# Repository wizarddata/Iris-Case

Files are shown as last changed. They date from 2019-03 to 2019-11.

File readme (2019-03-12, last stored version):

As of 3/12/2019 this case has not been tested. If you print one of these for a build let me know and I'1l remove this warning.

This is a tenting case for the Iris. This case is designed for 3/32 silicon feet on the underside of the PCB. 

You'll need to get the pro micro as close as you can to the PCB, the cheapest way to do this is remove the black plastic from the pin headers. 
Be sure to trim switch legs under the micro and use a piece of tape for electrical insulation.

Uses standard 3mm hardware. You'll need four (4) bolts (I recommend thumbscrews) 16mm - 20mm long, four (4) nuts, and eight (8) 5mm diameter magnets for each half. 

The magnets will need to be glued in place. The hat is a press fit into the switchplate and there are provisions to add some adhesive after assembly if necessary.

To improve traction, wrap a #30 rubber band around each leg lengthwise. Compatible with Ergodox EZ legs as well.

The units of these models are in inches.

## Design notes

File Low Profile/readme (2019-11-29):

These files are not compatible with the rest of the files in this repo.

This is a tenting case for the Iris. This case is designed for 3/32 silicon feet on the underside of the PCB.

Uses standard 3mm hardware. You'll need bolts (I recommend thumbscrews) about 16mm long.

To improve traction, wrap a #30 rubber band around each leg lengthwise.

EDIT 15-Mar-2019 - Case updated to allow for more room for the pro micro.

https://a360.co/2Y1DsCQ

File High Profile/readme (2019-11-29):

This is a tenting case for the Iris. This case is designed for 3/32 silicon feet on the underside of the PCB. 

Uses standard 3mm hardware. You'll need four (4) bolts (I recommend thumbscrews) 16mm long, four (4) nuts, and eight (8) 5mm diameter magnets for each half. 

You'll need to get the pro micro as close as you can to the PCB. There is ~0.25" between the bottom of the pcb and the case.
I recommend peel-a-way sockets, available at keeb.io, but the cheapest way to do this is remove the black plastic from the pin headers that came in your kit.
Be sure to trim switch legs under the micro and use a piece of tape for electrical insulation.

The hat and magnets will need to be glued in place. The switchplate has provisions to add some adhesive to the locating pins on the hat from the underside.
Attach the hat to the switchplate before you solder any switches onto your pcb.

To improve traction, wrap a #30 rubber band around each leg lengthwise. Compatible with Ergodox EZ legs as well.

Model units are mm.

https://a360.co/2swS4hT

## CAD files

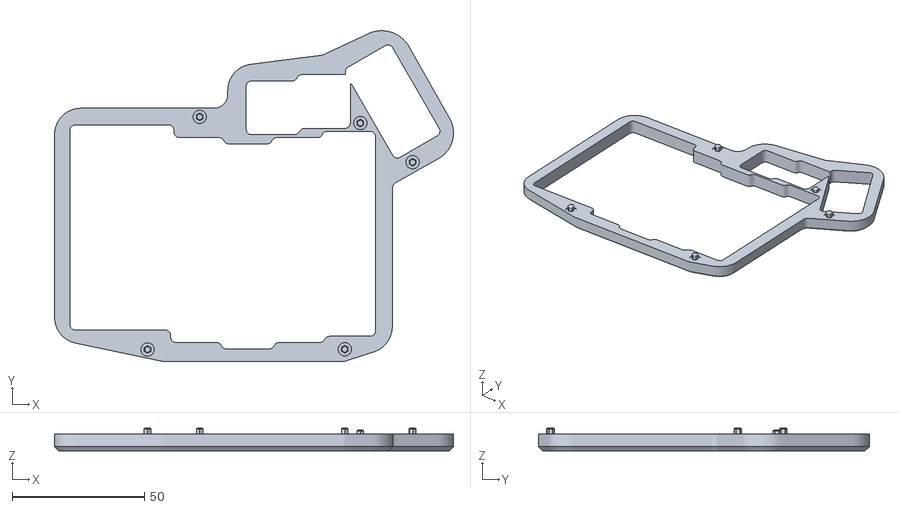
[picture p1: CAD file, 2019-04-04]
High Profile/Hat - Left.stl
150.9 x 125.0 x 8.64

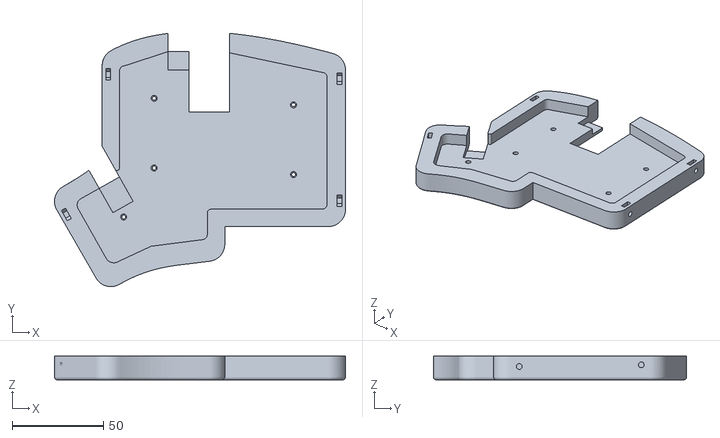
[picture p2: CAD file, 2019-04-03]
Interior Standoff Plate/Case - Right.stl
159.1 x 138.4 x 13.0

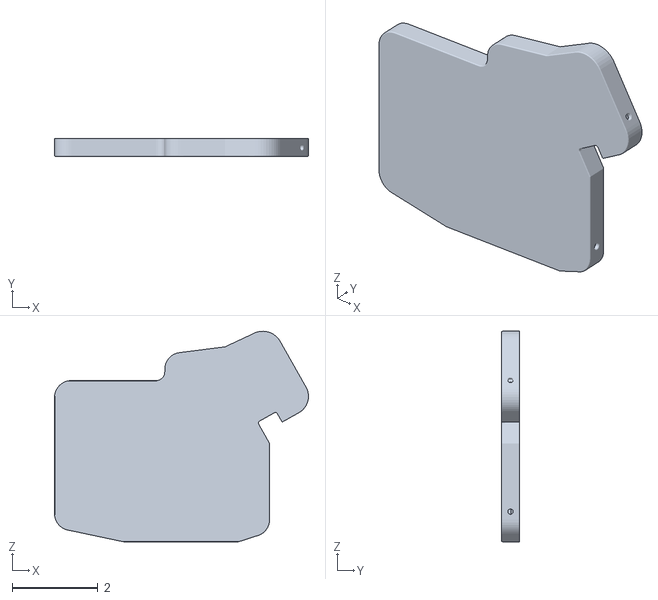
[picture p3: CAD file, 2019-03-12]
Iris Case - Left.stl
5.94 x 0.415 x 4.92

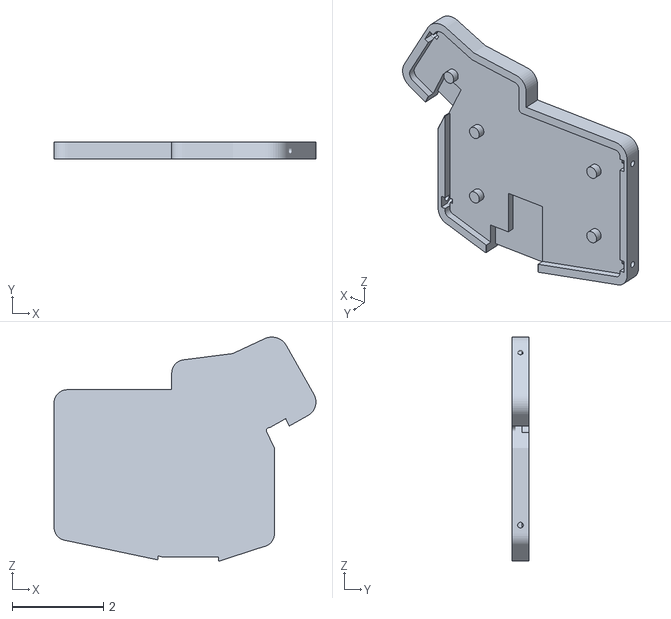
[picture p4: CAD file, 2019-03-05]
Low Profile Case/Iris Case - Left.stl
5.74 x 0.375 x 4.90

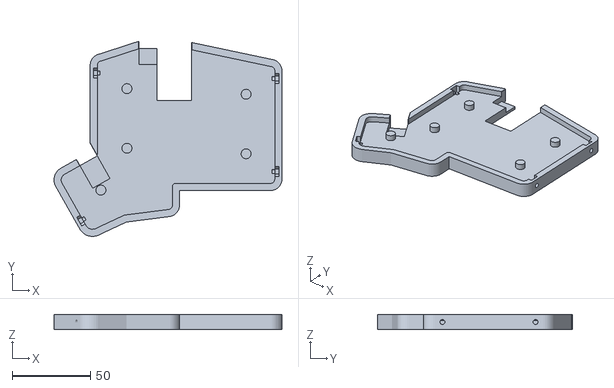
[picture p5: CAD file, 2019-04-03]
Low Profile/Low Profile Iris Case - Right.stl
145.8 x 124.6 x 9.53

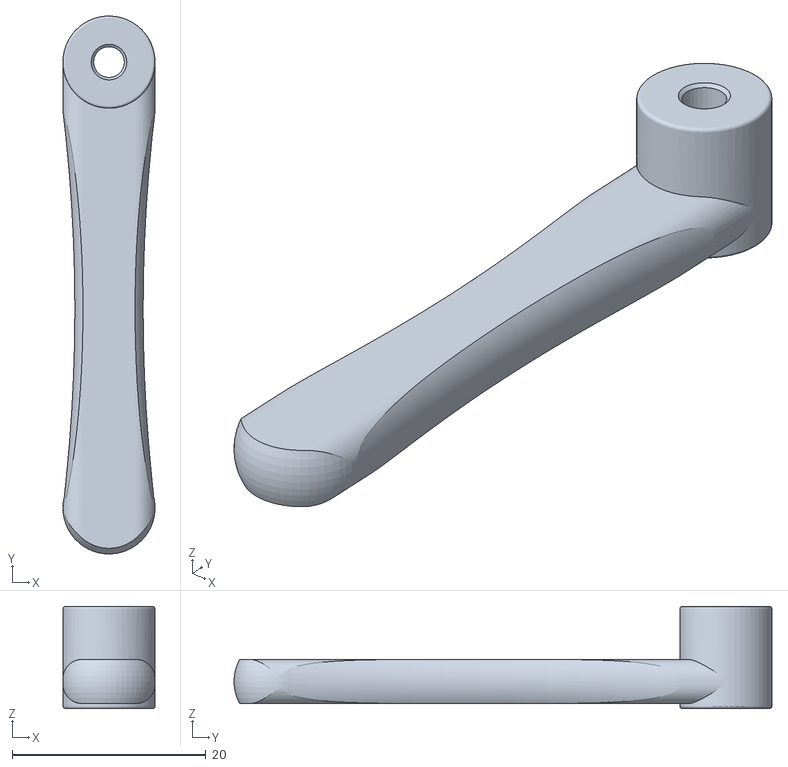
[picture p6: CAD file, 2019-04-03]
Low Profile/Legs v7.stl
9.52 x 55.6 x 10.5

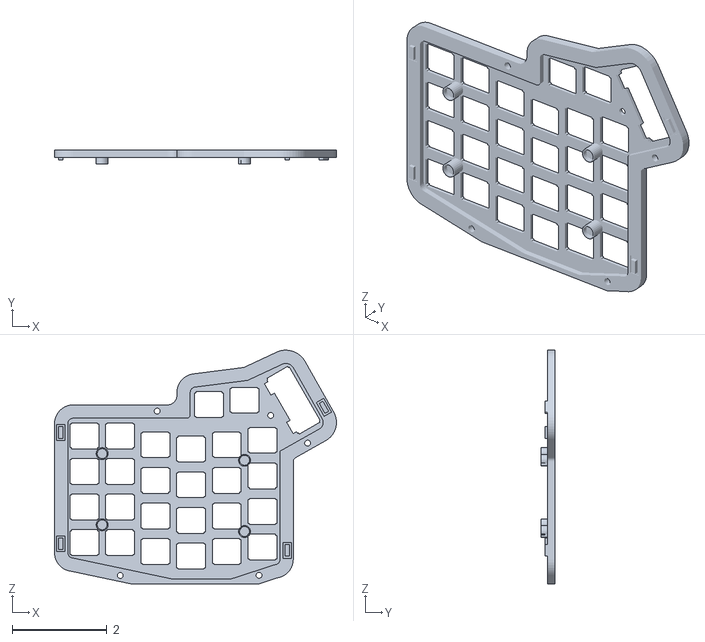
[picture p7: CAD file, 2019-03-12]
Switchplate - Left.stl
5.94 x 0.295 x 4.92

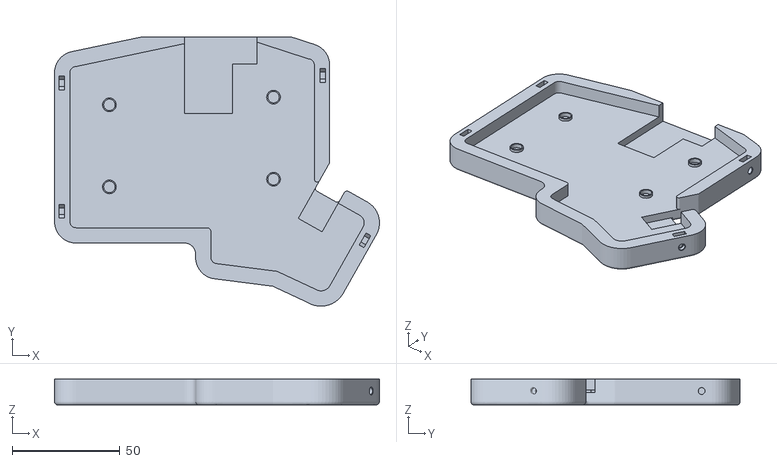
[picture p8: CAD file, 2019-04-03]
High Profile/Case - Left.stl
150.9 x 125.0 x 12.1

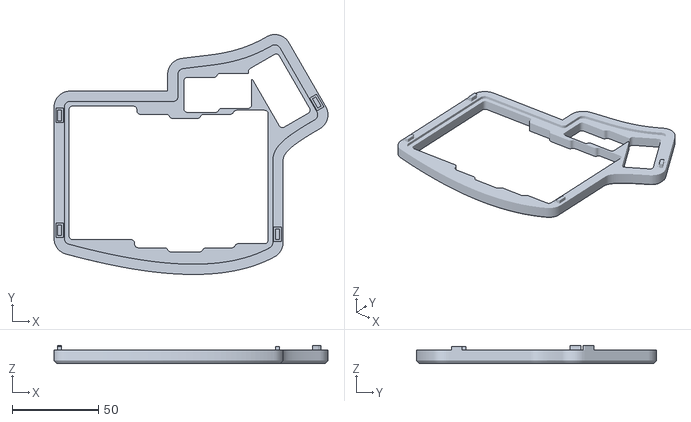
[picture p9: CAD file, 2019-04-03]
Interior Standoff Plate/Hat - Left.stl
159.1 x 139.3 x 10.5

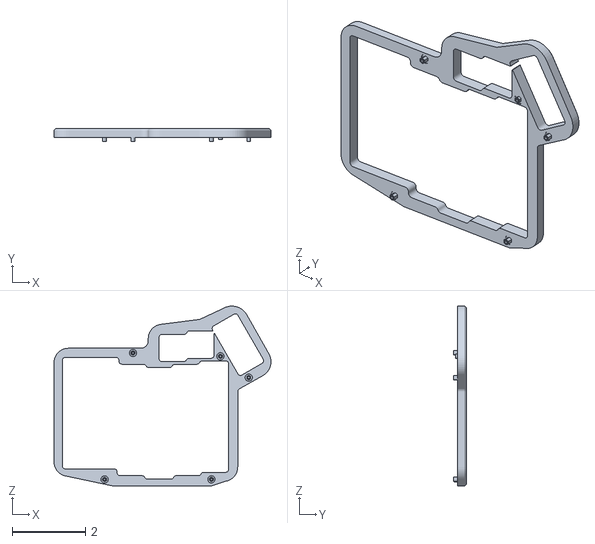
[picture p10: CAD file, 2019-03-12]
Hat - Left.stl
5.94 x 0.36 x 4.92

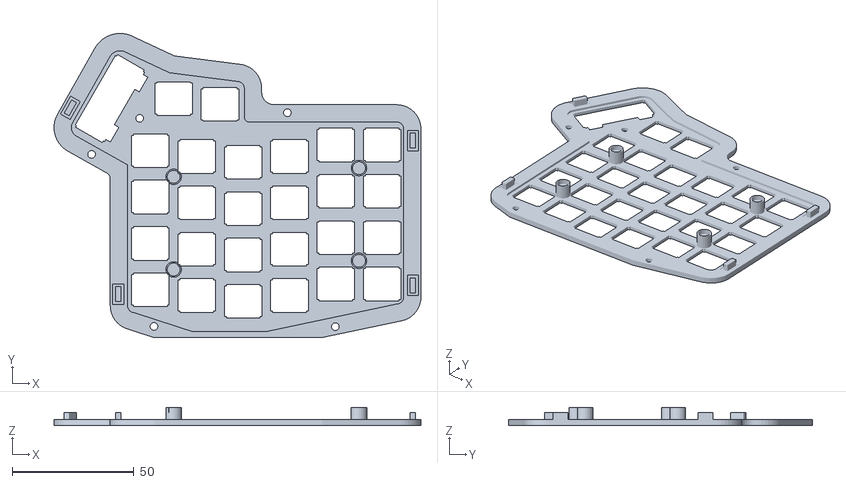
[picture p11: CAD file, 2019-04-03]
High Profile/Switchplate - Right.stl
150.9 x 125.0 x 7.49

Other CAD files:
High Profile/Hat - Right.stl
Interior Standoff Plate/Case - Left.stl
Low Profile Case/Iris Case - Right.stl
Iris Case - Right.stl
Low Profile/Low Profile Iris Case - Left.stl
Interior Standoff Plate/Hat - Right.stl
High Profile/Case - Right.stl
Hat - Right.stl
High Profile/Switchplate - Left.stl
Switchplate - Right.stl

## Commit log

2019-03-15 Updated Case
    Added additional space for the pro micro.
    [Iris Case - Left Rev 0.stl, Iris Case - Right Rev 0.stl, Leg.stl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]
2019-03-18 Rev 1 Upload
    [Case - Left.stl, Case - Right.stl, Hat - Left Rev 0.stl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]
2019-03-18 File Structure Update
    [Iris Case - Left Rev 0.stl, Iris Case - Right Rev 0.stl, Leg.stl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]
2019-03-21 Clearance Tweak
    Added clearance next to the trrs jack by applying a fillet
    [Case - Left.stl, Case - Right.stl]
2019-03-29 Added support for interior standoff top plate
    [Case - Left.stl, Case - Right.stl, Hat - Left.stl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]
2019-03-29 Forgot the Leg
    [Leg.stl]
2019-04-03 Reupload in mm
    [Case - Left.stl, Case - Right.stl, Hat - Left Rev 0.stl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]
2019-04-04 Corrected error with high profile hat
    [Hat - Left.stl, Hat - Right.stl]
